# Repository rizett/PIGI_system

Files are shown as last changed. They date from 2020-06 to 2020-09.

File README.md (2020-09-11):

# PIGI_system
This repository (doi. 10.5281/zenodo.4024952) contains Matlab, LabVIEW and AutoIt software scripts to acquire and process data from the PIGI system (Izett & Tortell, 2020; Oceanography). Technical and CAD drawings are also provided.

The LabVIEW files contain scripts to acquire, display and record underway deployment data. LabVIEW files were written using version 2019, SP1. The base, full and professional development programs (require license) can be downloaded here: https://www.ni.com/en-ca/support/downloads/software-products/download.labview.html#329059. The provided installer contains the 2019 runtime engine, or it can be downloaded separately from https://www.ni.com/en-ca/support/downloads/software-products/download.labview.html#346878. 

The AutoIt files contain scripts to automatically re-start underway data acquisitions. AutoIt can be downoloaded freely here: https://www.autoitscript.com/site/autoit-tools/

The Matlab files contain scripts to read and process deployment data. An example dataset is provided. These scripts are not compatible with Octave.

The technical diagrams contain specifications for machining components of the PIGI system. Diagrams were produced using Solidworks, and can be viewed without a license. Additional Solidworks files, containing 3D CAD assembly diagrams are also included. 

References:
Izett, R. & Tortell, P. 2020. The Pressure of in-situ Gases Instrument (PIGI) for autonomous ship-board measurement of dissolved O2 and N2 in surface ocean waters. Oceanography. 33(2).https://doi.org/10.5670/oceanog.2020.214.

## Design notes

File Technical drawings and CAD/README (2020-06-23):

This folder contains technical drawings for the machined PIGI components and Solidworks 3D CAD software files.

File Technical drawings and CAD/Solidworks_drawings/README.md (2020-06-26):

This folder contains Solidworks files to visualize 3D CAD drawings. 

Open PIGI4.3_2020.SLDASM to view the assembled components, and PIGI_4.3_Part-Drawings.SLDDRW to view the part drawings (saved as PIGI4.3_Technical-drawings.PDF)

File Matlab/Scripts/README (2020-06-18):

This folder contains the scripts and functions to read and process PIGI data obtained from LabVIEW acquisitions. 

Run "process_pigi_MAIN.m" to peform the processing.

Note that additional hydrographic data (temperature and salinity), and atmospheric sea level pressure are required to perform post-processing calculations.

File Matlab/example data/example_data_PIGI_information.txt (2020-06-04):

Cruise Name: example_data
Cruise ID: ex-dat
Ship: Black Pearl
Operator Name: Izett
Optode Serial No.: 4330-2941
TDGP (mini) Serial No.: 37-465-31
Pump Type: Magnetic Drive
Instrument Location: Main Lab
Loop Calibration Samples Obtained?: YES
Time offset from TSG: 0 Hr, 3 Min, 18 Sec Behind
Data headers:
Computer JD
O2%
O2 uM
Opt. temp
mini mbar
mini temp
Flow rate [l/min]
GPS JD
GPS Lat
GPS Long
Opt raw CalPhase
Opt raw TC Phase
Opt raw C1RPh
Opt raw C2RPh
Opt raw C1 amp
Opt raw C2 amp
Opt raw Raw temp
mini raw supply voltage
mini raw Analog in 1
mini raw Analog in 2
mini raw Digital in 1
mini raw Digital in 2
Pump status (on/off)
Primary flow rate [L/min]

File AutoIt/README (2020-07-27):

This folder contains an AutoIt (https://www.autoitscript.com/site/autoit-tools/) script to automatically re-start PIGI LabVIEW acquisitions. 

The script can be edited by opening the .au3 file. After making edits, the file MUST be re-compiled into an executable (.exe) file (Right click --> compile --> rename the compiled file as run_acquisition_compiled.exe). NOTE: the file does not need to be edited in its current form to work; only edits for alternative functionality should be made as desired by the user.  

The .exe file must be referenced in the autoPIGI_underway_2020 LabVIEW program.

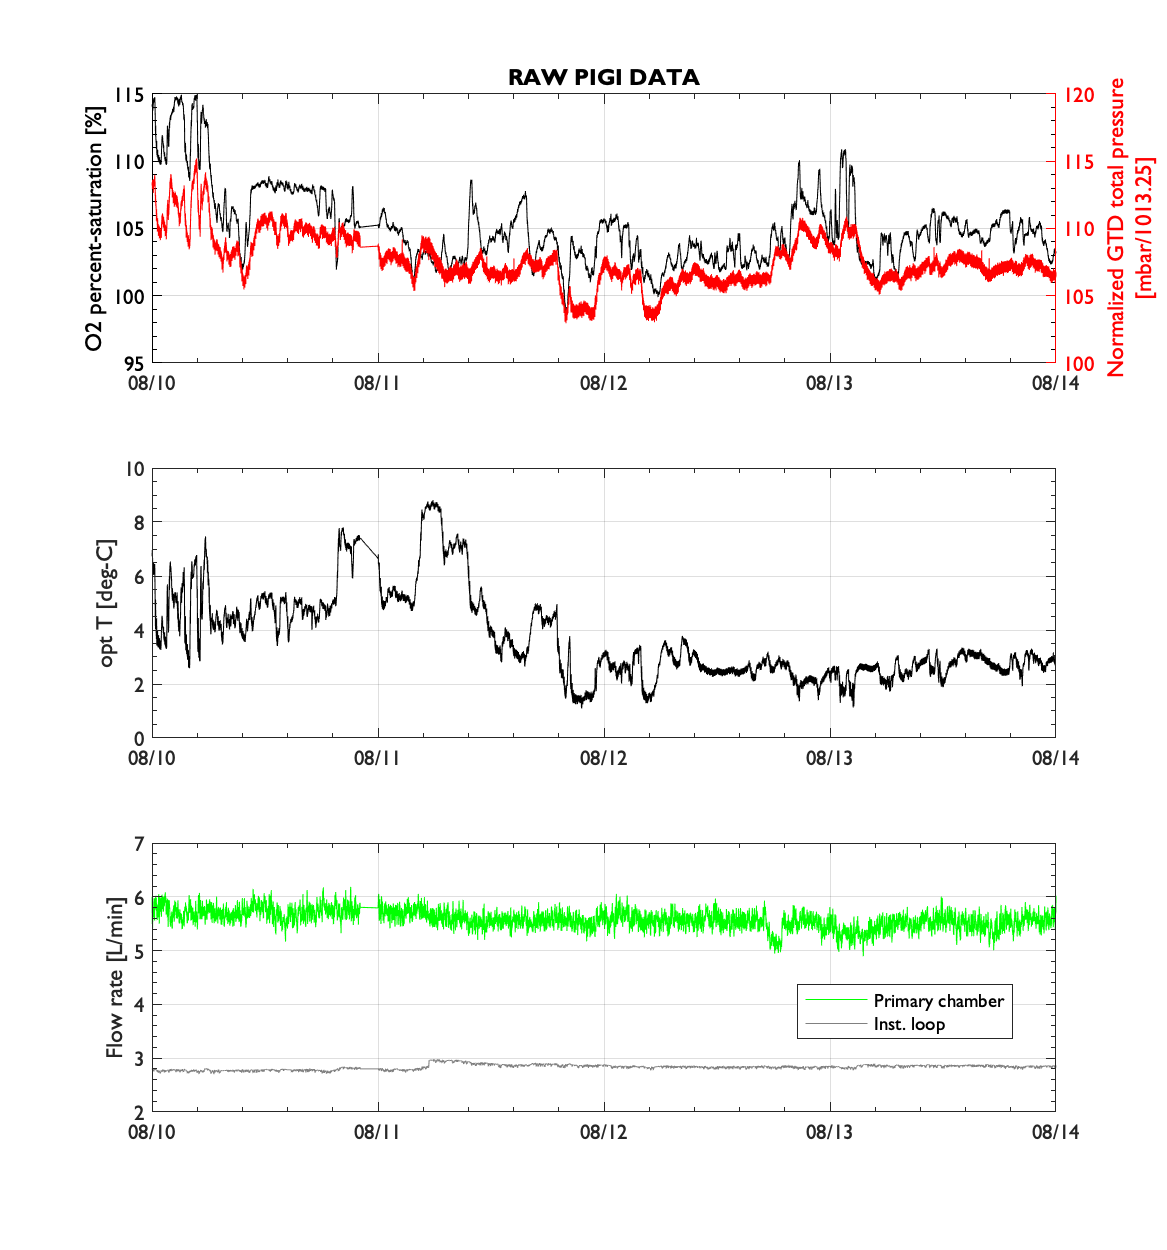
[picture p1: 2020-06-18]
Matlab/example data/example_deployment_PIGI_RAW_v20200618.tif

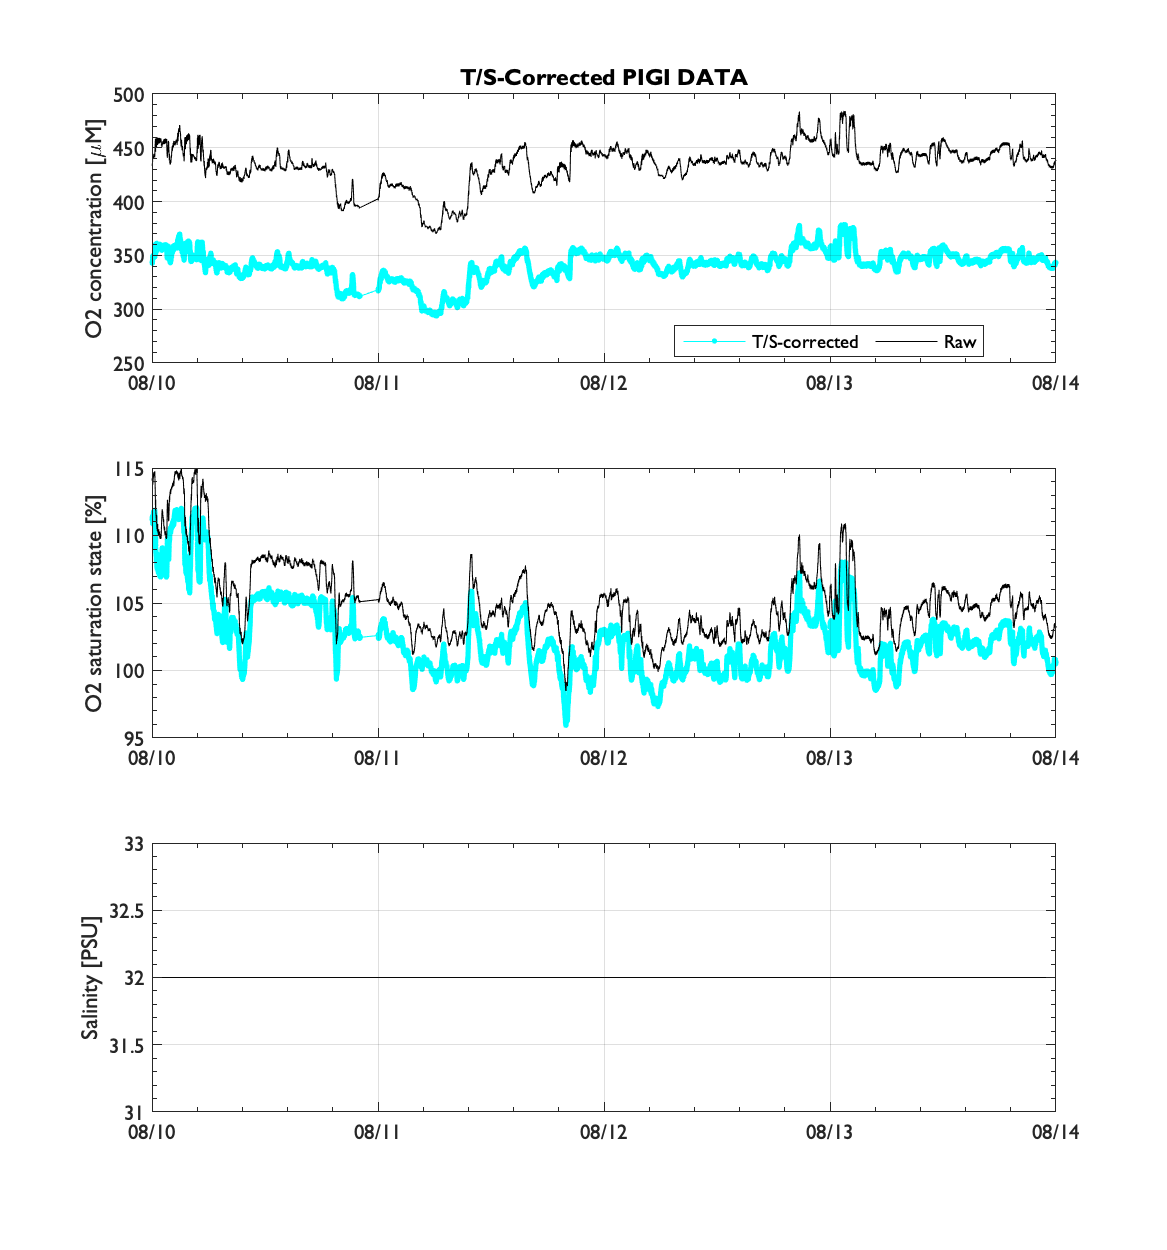
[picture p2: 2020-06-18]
Matlab/example data/example_deployment_PIGI_O2-TS-Comp_v20200618.tif

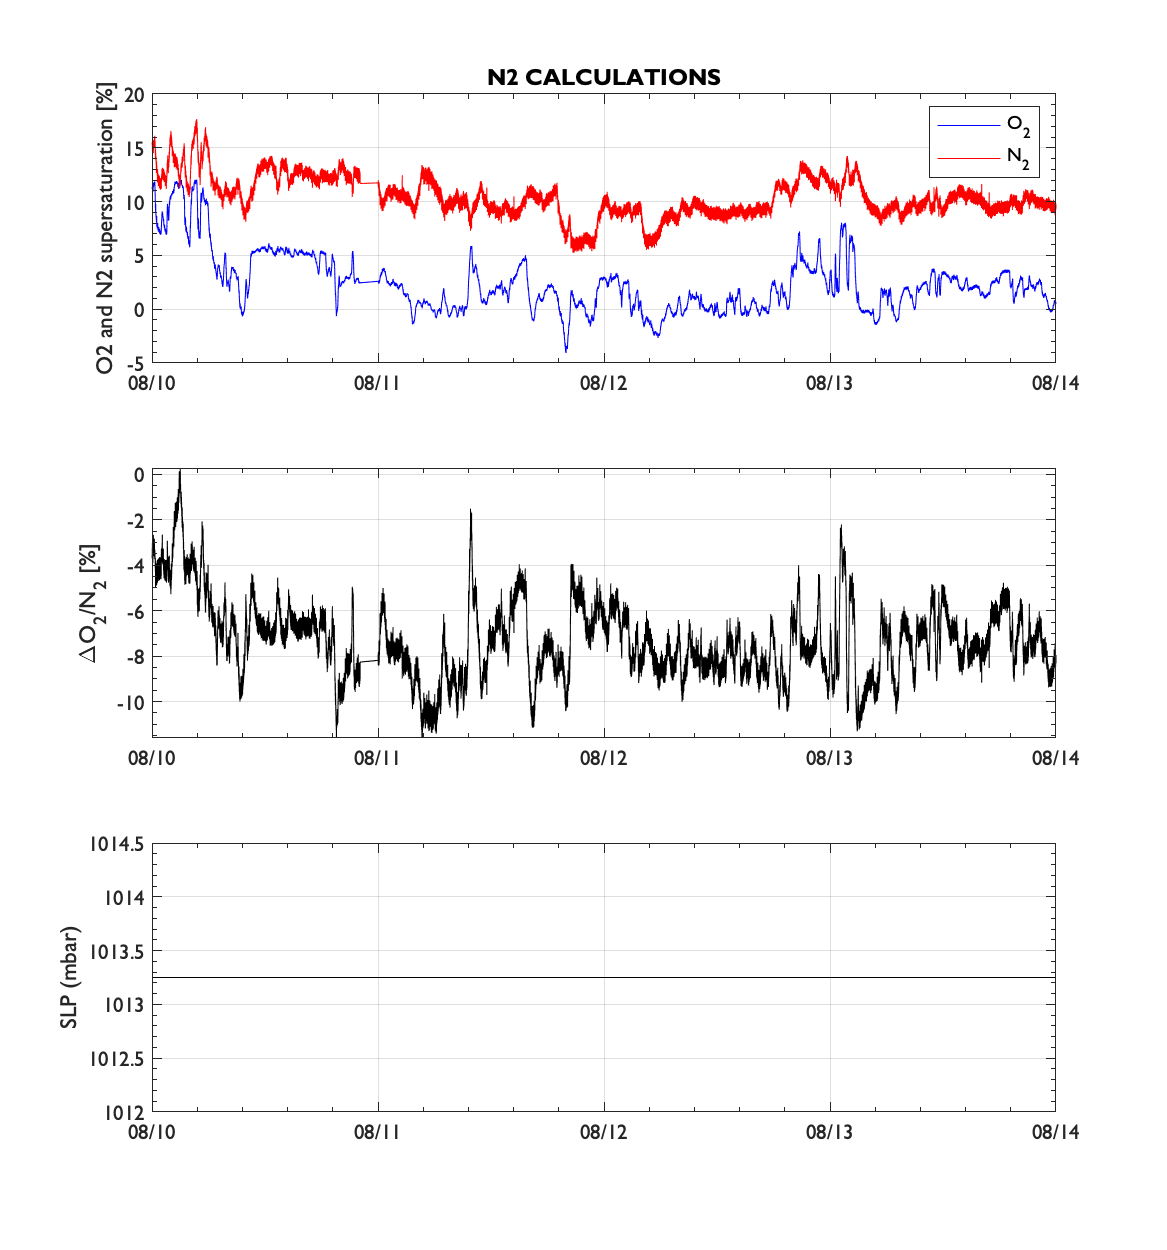
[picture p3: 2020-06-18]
Matlab/example data/example_deployment_PIGI_N2_calc.mat_v20200618.tif

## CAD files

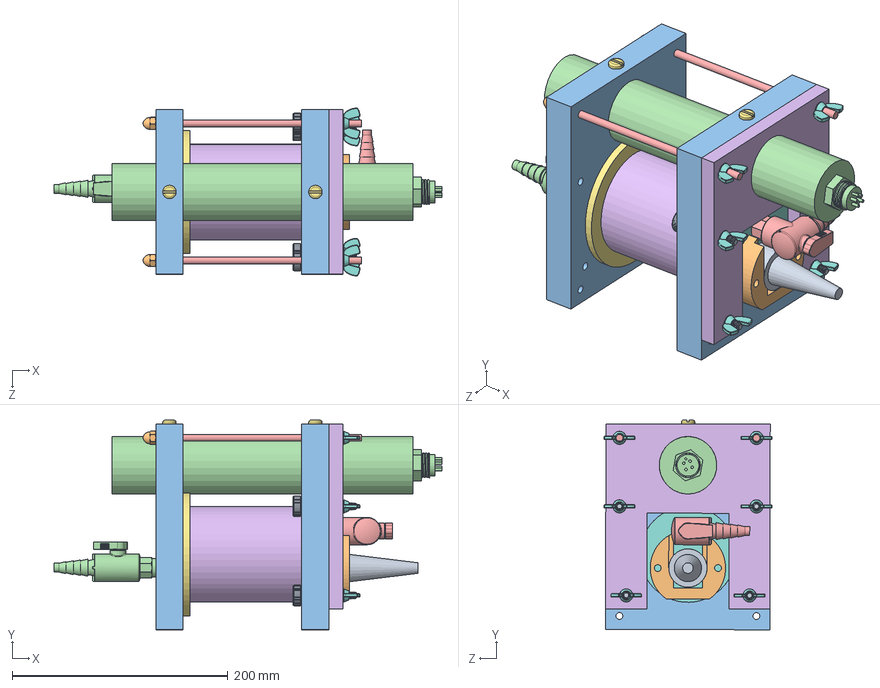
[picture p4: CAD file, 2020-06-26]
Technical drawings and CAD/Solidworks_drawings/PIGI4.3_Instrument-Chamber.SLDASM
359.6 x 194.2 x 155.6 mm
PIGI4.3_Thumb-Screw_Part34 x 4
PIGI4.3_Acorn-Nut_Part31 x 2
PIGI4.3_Optode-Chamber-Support_PartG x 2
PIGI4.3_mini-TDGP_Part2
PIGI4.3_8in-SS-rod_Part32 x 2
PIGI4.3_Optode-chamber-tube_PartC
PIGI4.3_Optode-Chamber-Inflow-Cap_PartJ
PIGI4.3_Optode-Chamber-Outflow-Cap_PartI
PIGI4.3_Optode_Part1
PIGI4.3_Optode-Support_PartK
PIGI4.3_Optode-Chamber-Outflow-Oring_Part15
PIGI4.3_Straight-Valve_Part18
PIGI4.3_Elbow-Valve_Part19
PIGI4.3_Optode-Chamber-Outflow-Stopper_PartH
PIGI4.3_Teflon-screw_Part35 x 2
PIGI4.3_Wing-Nut_Part30 x 6

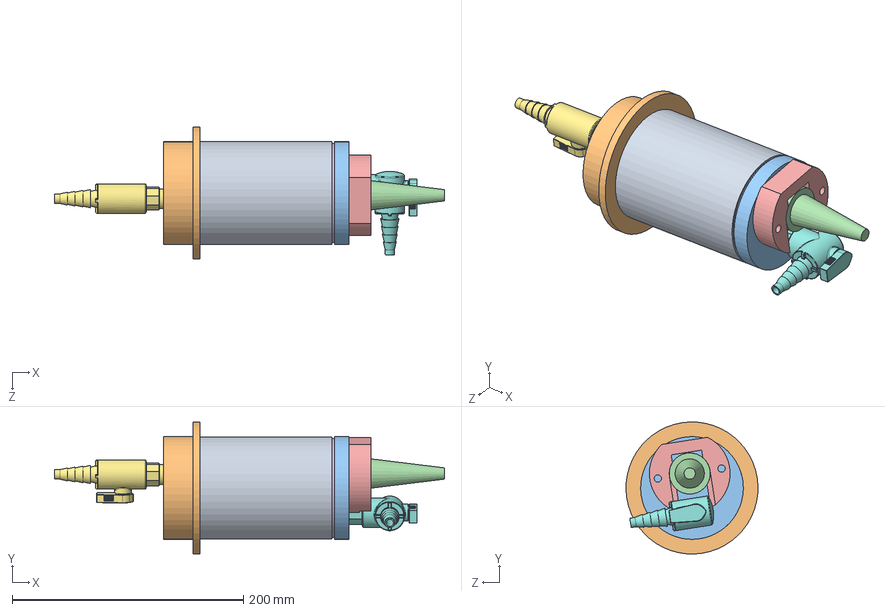
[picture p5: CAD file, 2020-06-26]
Technical drawings and CAD/Solidworks_drawings/PIGI4.3_Optode_chamber.SLDASM
337.6 x 114.2 x 114.2 mm
PIGI4.3_Optode-chamber-tube_PartC
PIGI4.3_Optode-Chamber-Inflow-Cap_PartJ
PIGI4.3_Optode-Chamber-Outflow-Cap_PartI
PIGI4.3_Optode_Part1
PIGI4.3_Optode-Support_PartK
PIGI4.3_Optode-Chamber-Outflow-Oring_Part15
PIGI4.3_Straight-Valve_Part18
PIGI4.3_Elbow-Valve_Part19

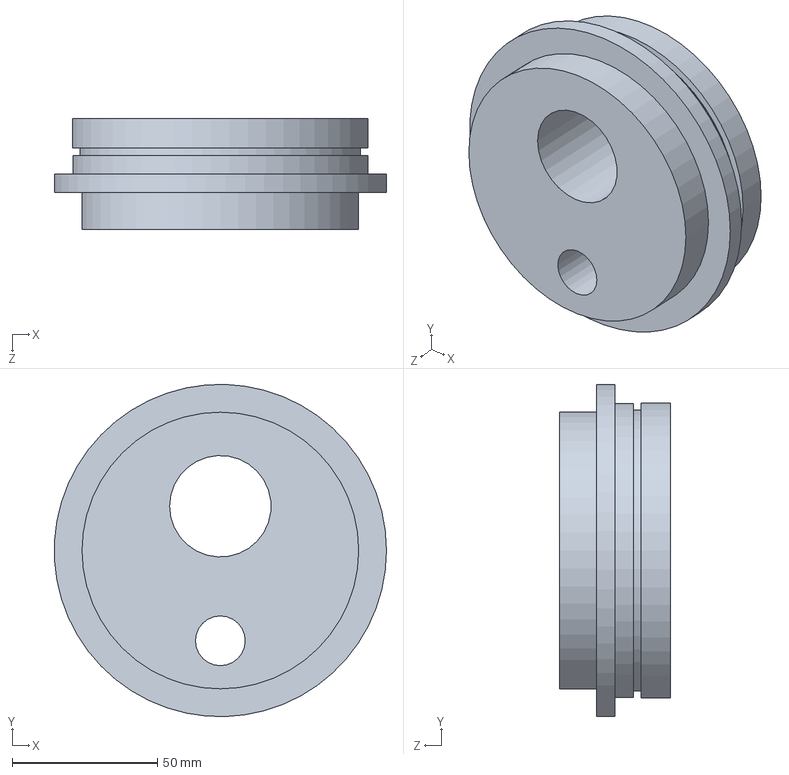
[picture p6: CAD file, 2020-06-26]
Technical drawings and CAD/Solidworks_drawings/PIGI4.3_Primary-chamber-inflow-cap_PartD.SLDPRT
114.3 x 114.4 x 38.1 mm

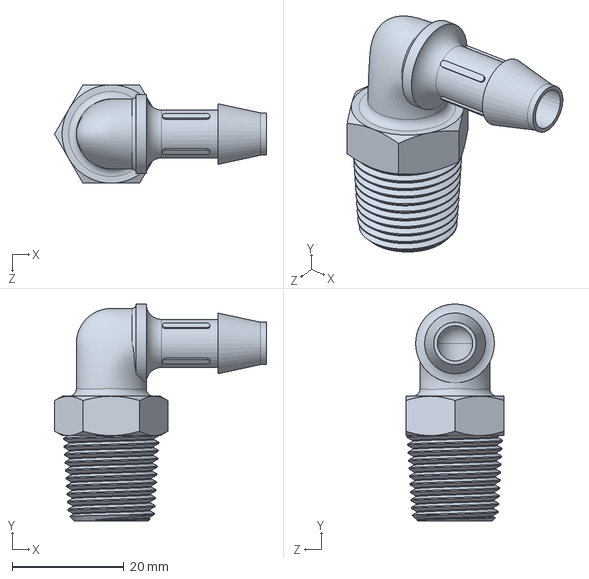
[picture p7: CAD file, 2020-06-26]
Technical drawings and CAD/Solidworks_drawings/PIGI4.3_Barbed-Adapter_Part27.SLDPRT
37.9 x 38.8 x 17.6 mm

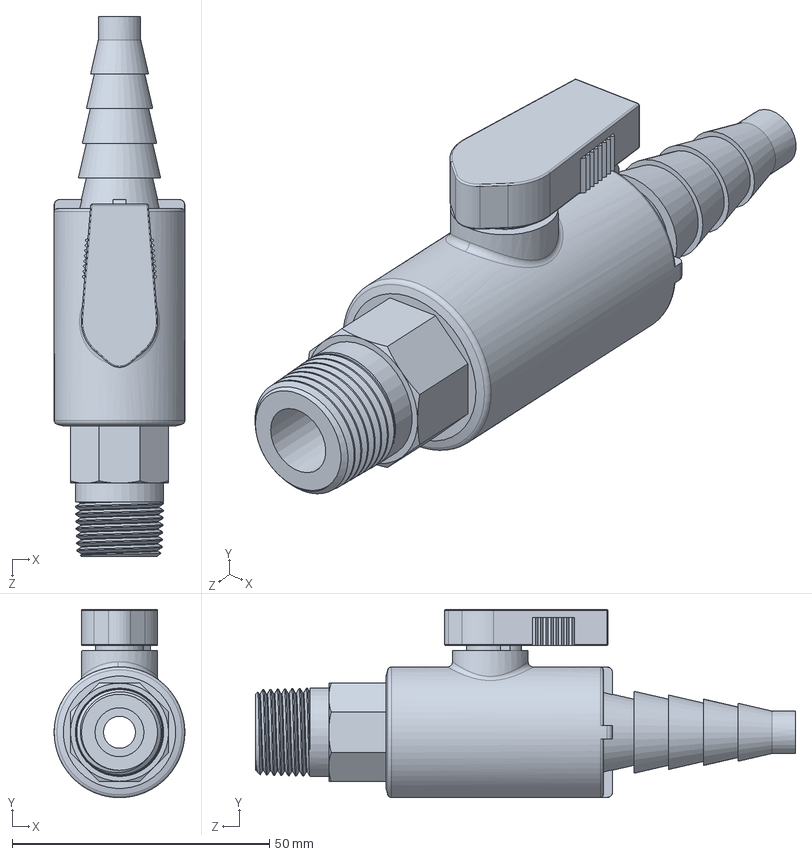
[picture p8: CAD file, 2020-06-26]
Technical drawings and CAD/Solidworks_drawings/PIGI4.3_Straight-Valve_Part18.SLDPRT
25.4 x 36.6 x 104.9 mm

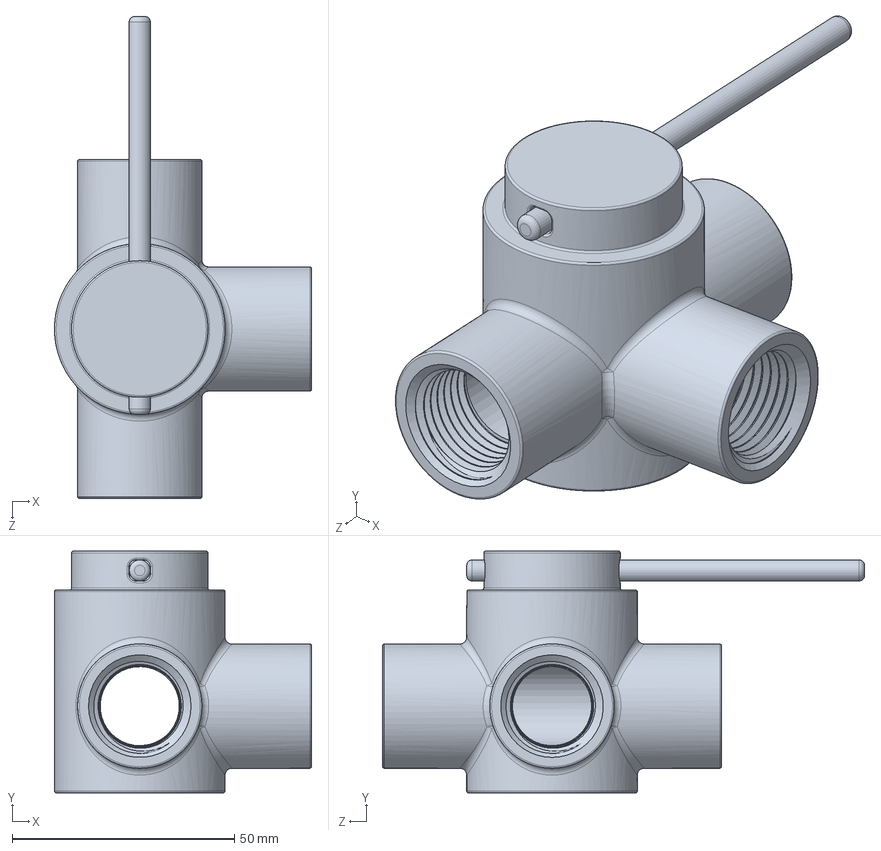
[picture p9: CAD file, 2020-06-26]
Technical drawings and CAD/Solidworks_drawings/PIGI4.3_3-Way-Valve_Part26.SLDPRT
57.8 x 54.4 x 108.3 mm

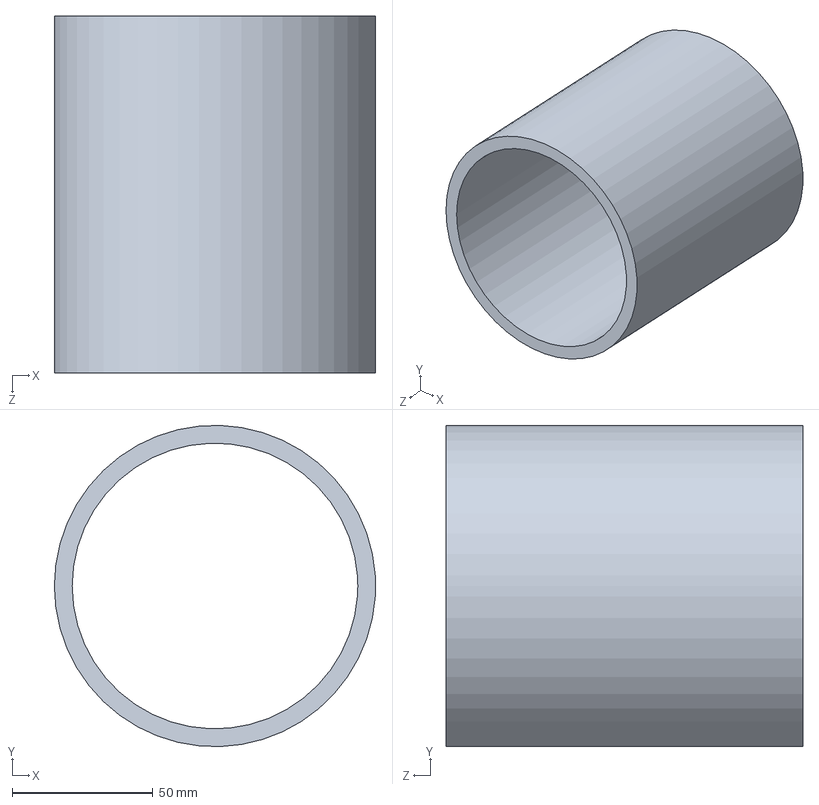
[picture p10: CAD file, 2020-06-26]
Technical drawings and CAD/Solidworks_drawings/PIGI4.3_Primary-chamber-tube-PartB.SLDPRT
114.3 x 114.2 x 127.0 mm

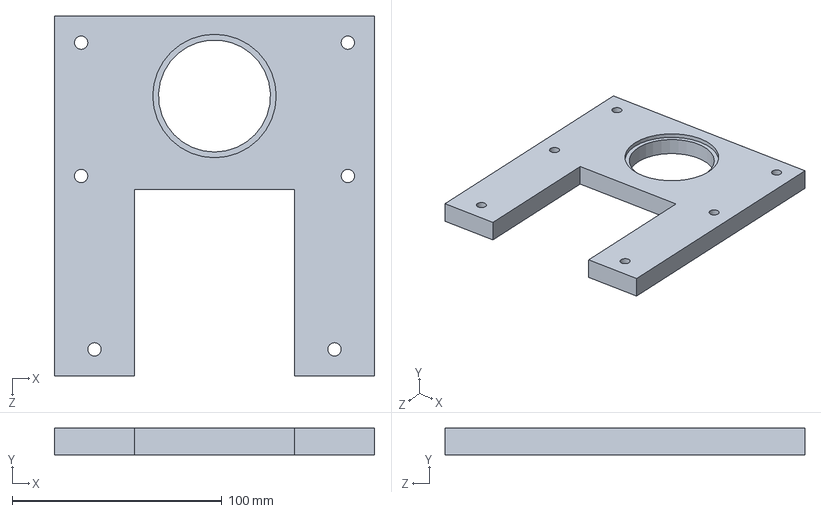
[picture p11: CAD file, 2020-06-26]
Technical drawings and CAD/Solidworks_drawings/PIGI4.3_Optode-Chamber-Outflow-Stopper_PartH.SLDPRT
152.4 x 12.7 x 171.4 mm

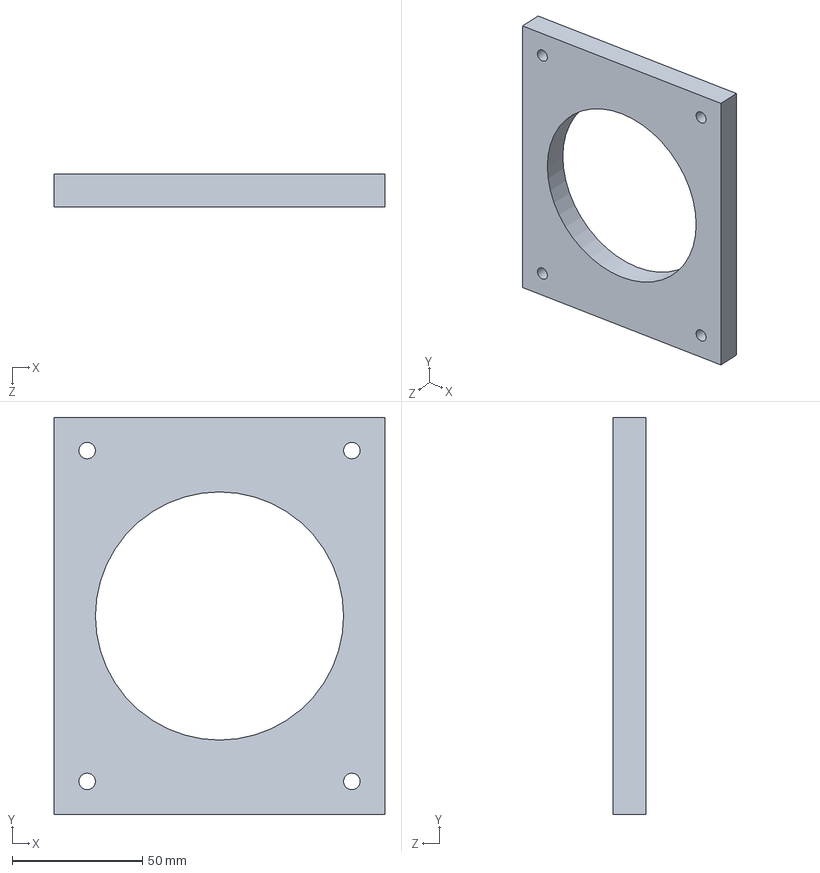
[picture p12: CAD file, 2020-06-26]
Technical drawings and CAD/Solidworks_drawings/PIGI4.3_Primary-chamber-supports_PartF.SLDPRT
127.0 x 152.4 x 12.7 mm

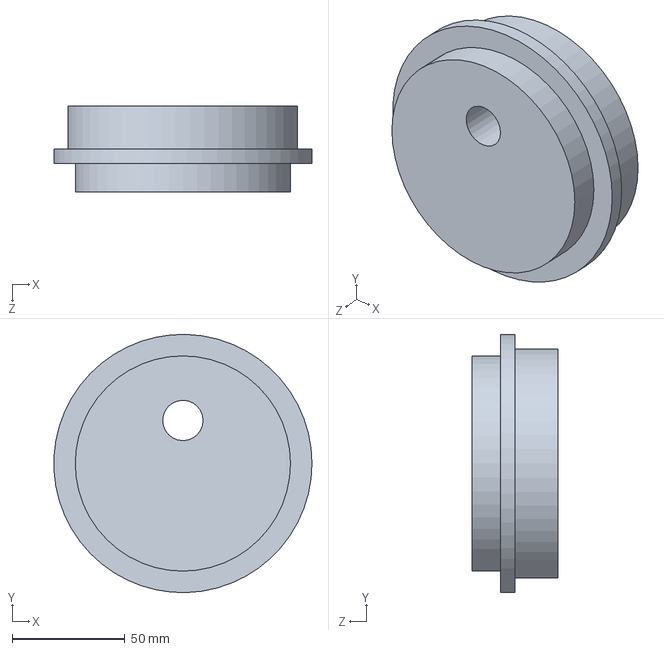
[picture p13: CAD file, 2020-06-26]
Technical drawings and CAD/Solidworks_drawings/PIGI4.3_Primary-chamber-outflow-cap_PartE.SLDPRT
114.2 x 114.2 x 38.1 mm

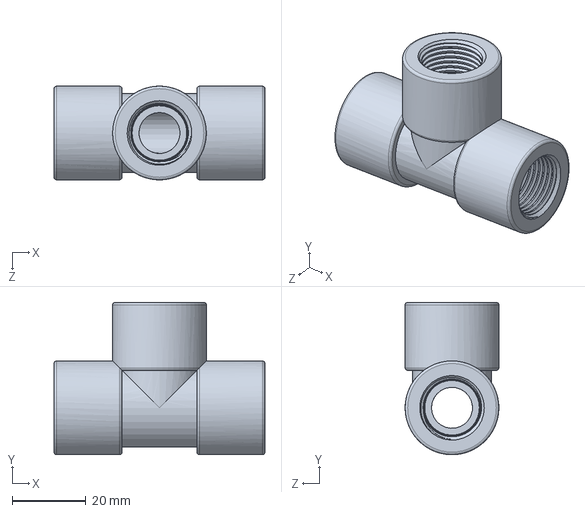
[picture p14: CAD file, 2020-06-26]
Technical drawings and CAD/Solidworks_drawings/PIGI4.3_T-Junction_Part22.SLDPRT
57.1 x 41.3 x 25.4 mm

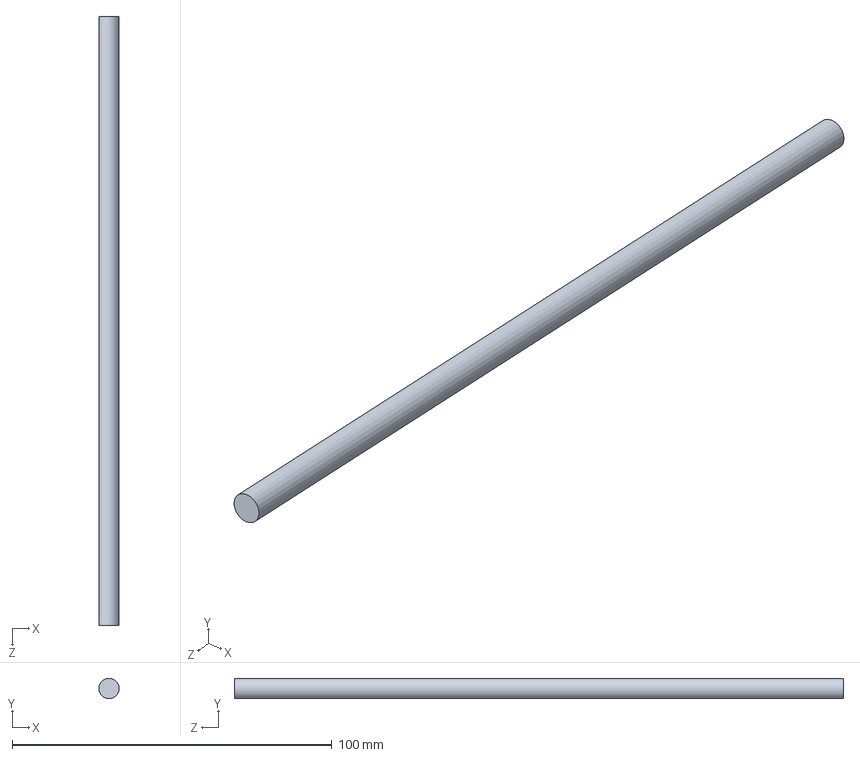
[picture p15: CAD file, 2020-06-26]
Technical drawings and CAD/Solidworks_drawings/PIGI4.3_8in-SS-rod_Part32.SLDPRT
6.35 x 6.35 x 190.5 mm

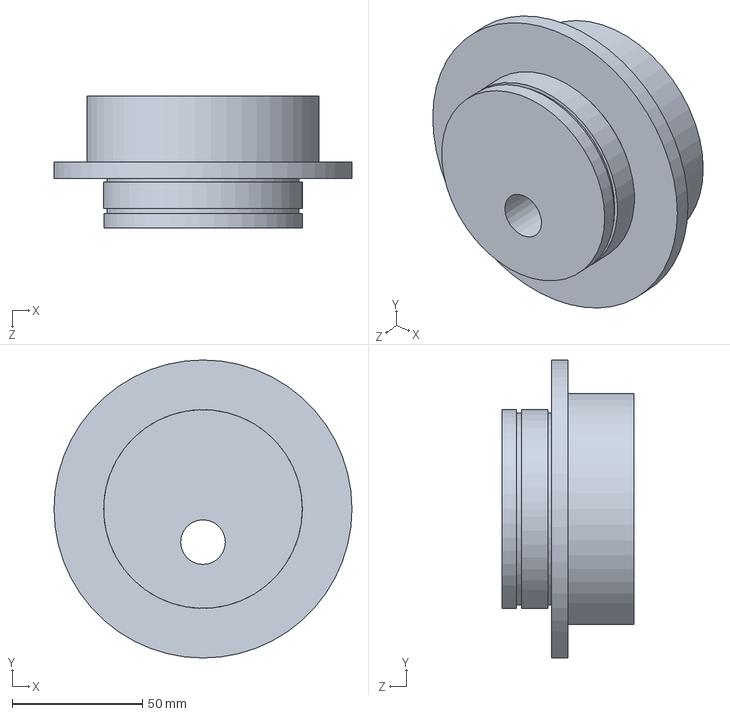
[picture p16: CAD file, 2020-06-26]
Technical drawings and CAD/Solidworks_drawings/PIGI4.3_Optode-Chamber-Inflow-Cap_PartJ.SLDPRT
114.3 x 114.3 x 50.8 mm

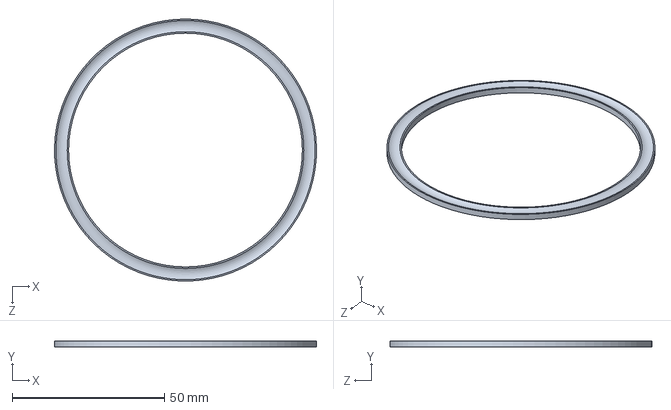
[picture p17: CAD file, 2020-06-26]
Technical drawings and CAD/Solidworks_drawings/PIGI4.3_Optode-Chamber-Outflow-Oring_Part15.SLDPRT
85.9 x 1.93 x 85.9 mm

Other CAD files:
Technical drawings and CAD/Solidworks_drawings/PIGI4.3_Optode-Chamber-Support_PartG.SLDPRT
Technical drawings and CAD/Solidworks_drawings/PIGI4.3_Check-Valve_Part25.SLDPRT
Technical drawings and CAD/Solidworks_drawings/PIGI4.3_Check-Valve_Part23.SLDPRT
Technical drawings and CAD/Solidworks_drawings/PIGI4.3_Debubbler-Tube_Part8.SLDPRT
Technical drawings and CAD/Solidworks_drawings/PIGI4.3_7in-SS-rod_Part32.SLDPRT
Technical drawings and CAD/Solidworks_drawings/PIGI4.3_9in-SS-rod_Part32.SLDPRT
Technical drawings and CAD/Solidworks_drawings/PIGI4.3_Acorn-Nut_Part31.SLDPRT
Technical drawings and CAD/Solidworks_drawings/PIGI4.3_Chamber-Base-PartA.SLDPRT
Technical drawings and CAD/Solidworks_drawings/PIGI4.3_Compression-Pads_Part36.SLDPRT
Technical drawings and CAD/Solidworks_drawings/PIGI4.3_Debubbler-Bulkhead-Connector_Part9.SLDPRT
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

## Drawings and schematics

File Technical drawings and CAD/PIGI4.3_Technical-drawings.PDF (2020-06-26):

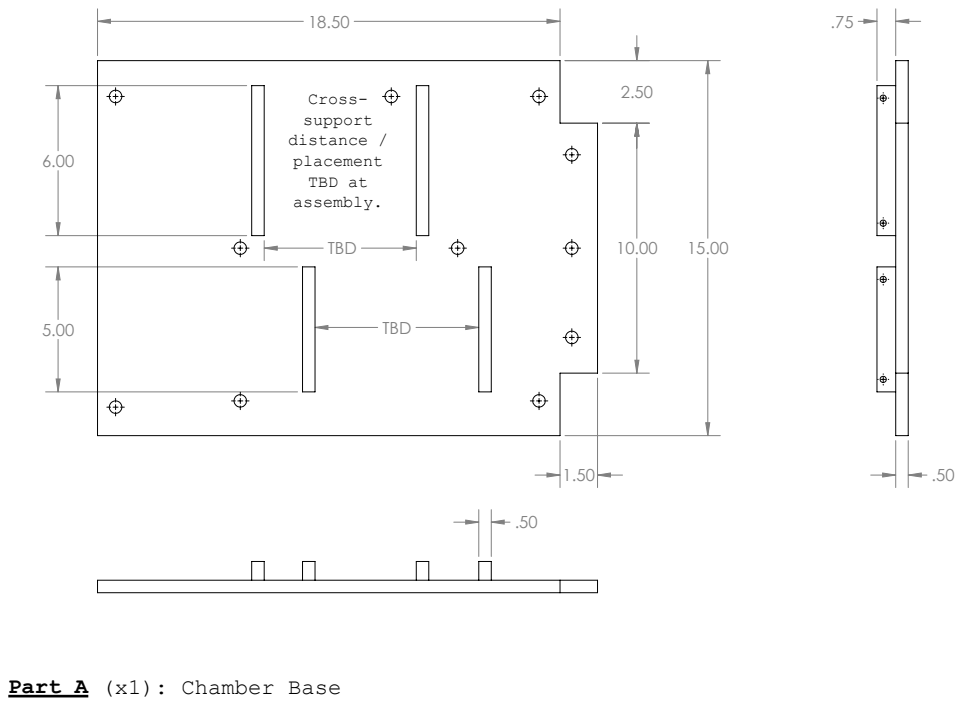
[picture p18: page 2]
distance / TBD at

Part A (x1): Chamber Base

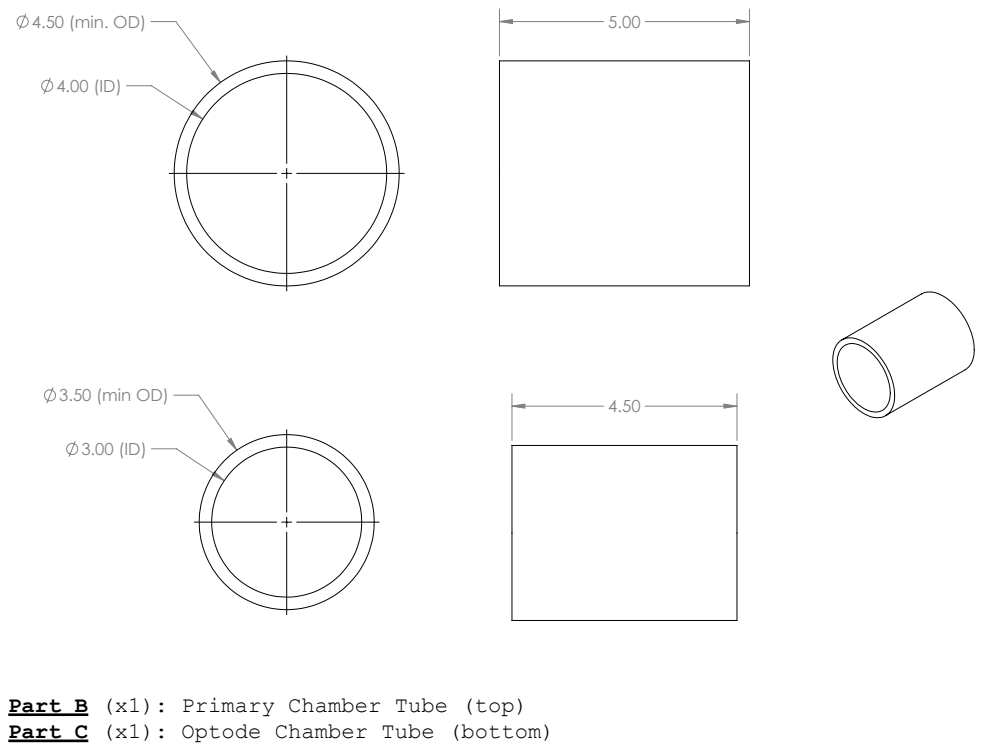
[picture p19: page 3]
4.50 (min. OD); 3.50 (min OD)

Part B (x1): Primary Chamber Tube (top)
Part C (x1): Optode Chamber Tube (bottom)

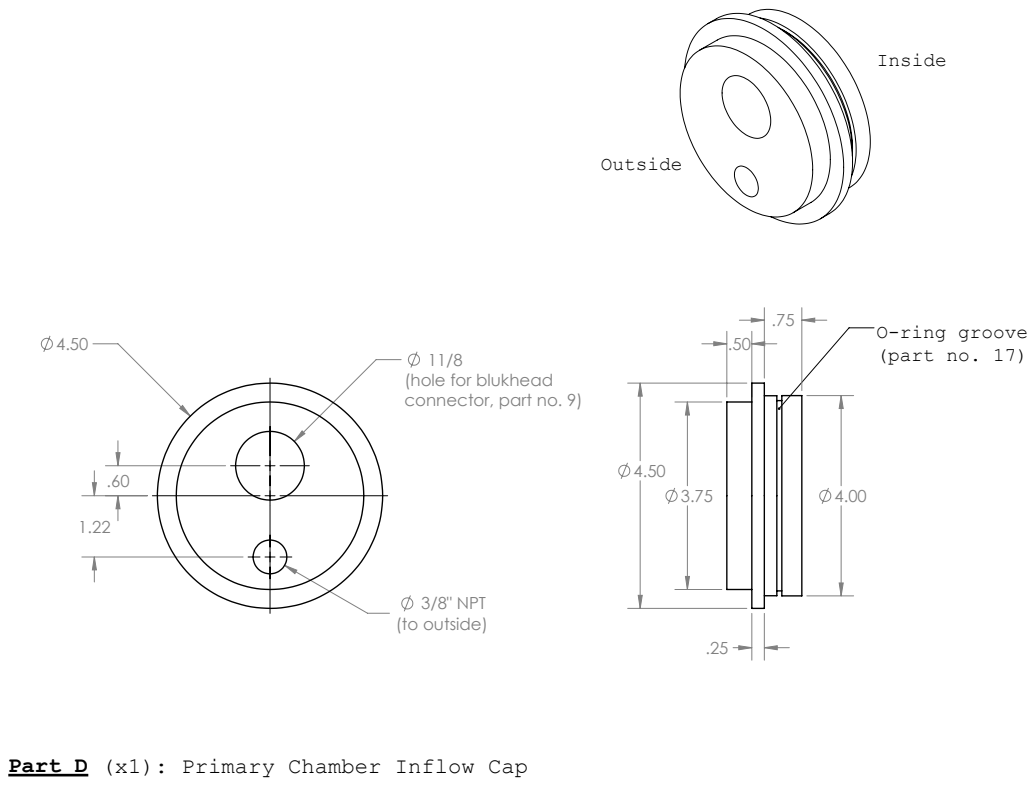
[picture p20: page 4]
3/8" NPT (to outside); O-ring groove (part no. 17)

(hole for blukhead
connector, part no. 9)

Part D (x1): Primary Chamber Inflow Cap

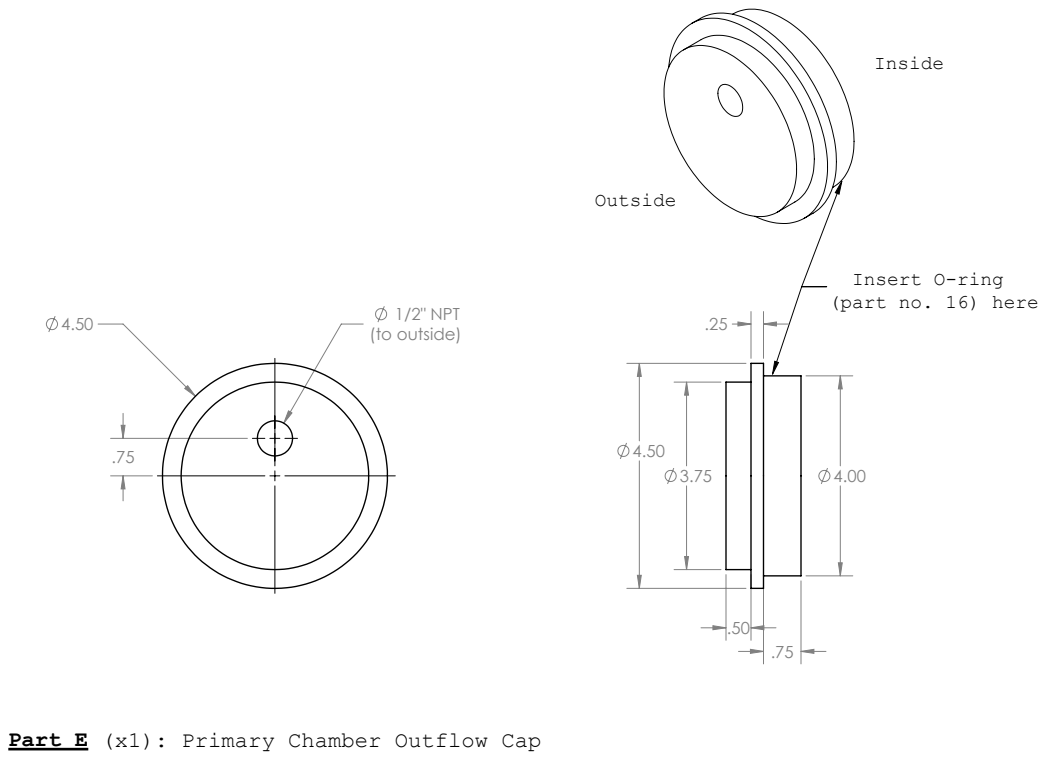
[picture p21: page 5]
1/2" NPT (to outside)

Insert O-ring
(part no. 16) here

Part E (x1): Primary Chamber Outflow Cap

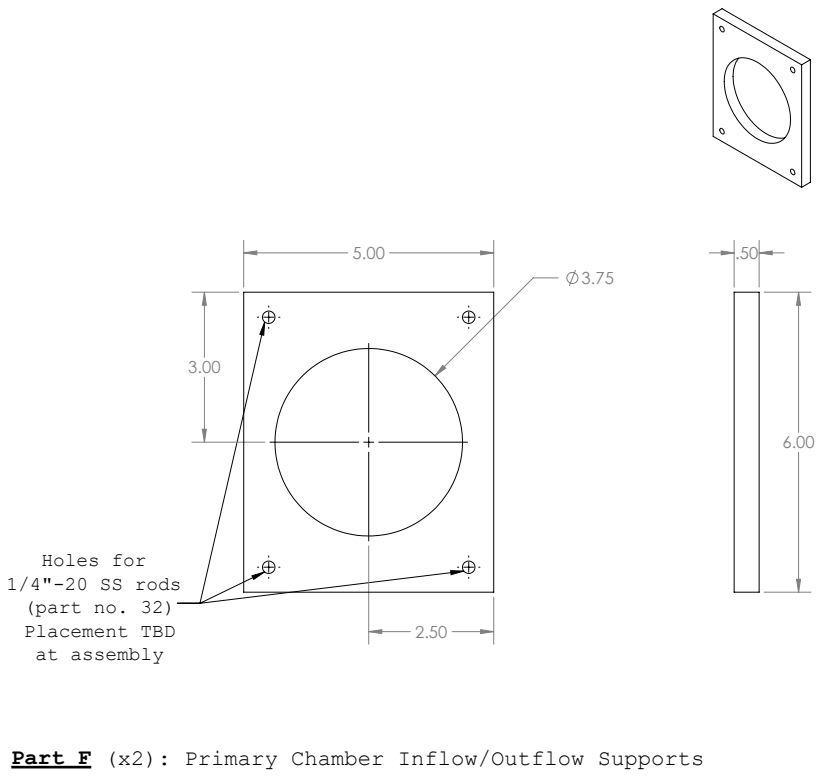
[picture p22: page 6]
Holes for 1/4"-20 SS rods (part no. 32) Placement TBD at assembly

Part F (x2): Primary Chamber Inflow/Outflow Supports

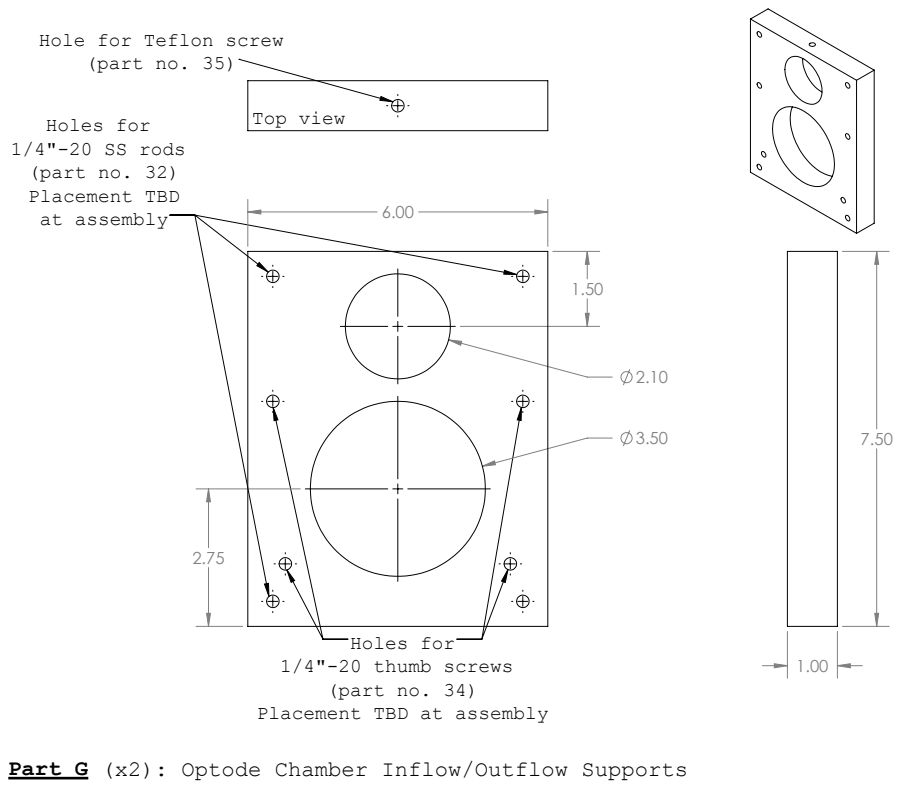
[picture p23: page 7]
Top view

Hole for Teflon screw
(part no. 35)
Holes for
1/4"-20 SS rods
(part no. 32)
Placement TBD
at assembly

1/4"-20 thumb screws
(part no. 34)
Placement TBD at assembly

Part G (x2): Optode Chamber Inflow/Outflow Supports

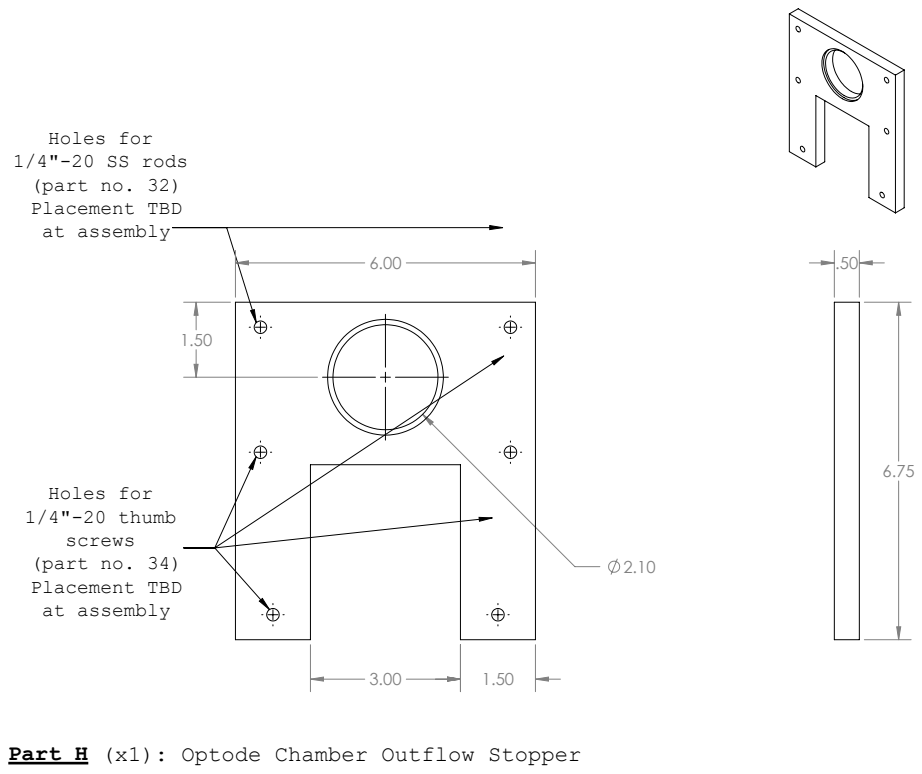
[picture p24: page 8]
Holes for 1/4"-20 SS rods (part no. 32) Placement TBD at assembly; Holes for 1/4"-20 thumb (part no. 34) Placement TBD at assembly

Part H (x1): Optode Chamber Outflow Stopper

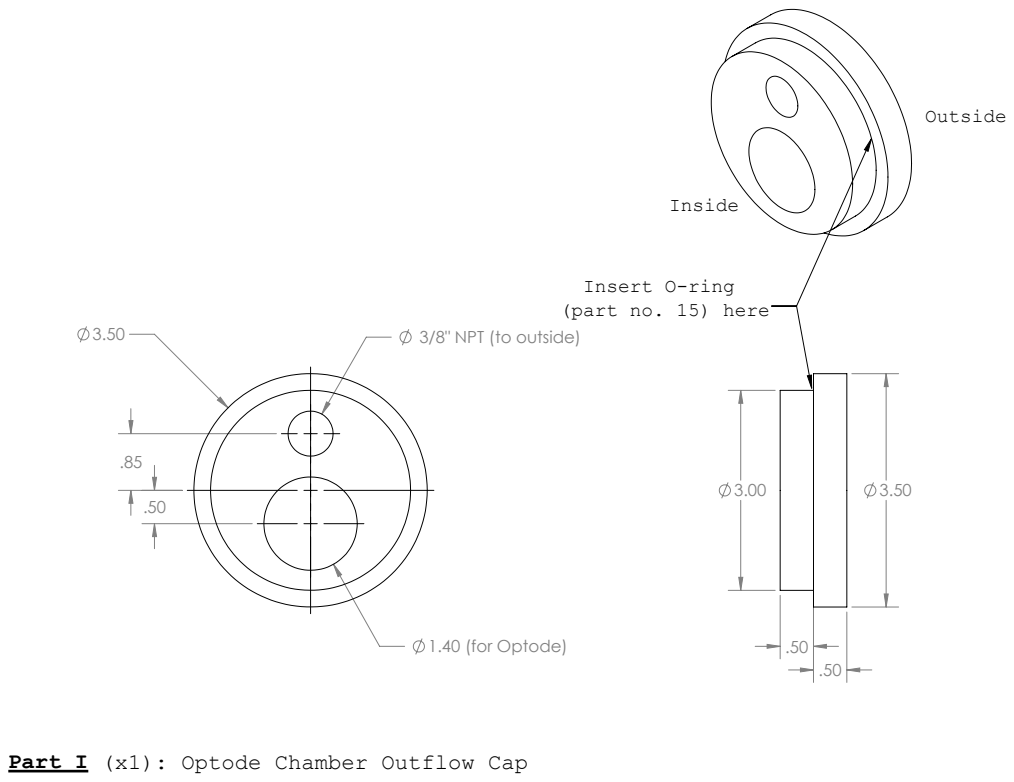
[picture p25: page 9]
1.40 (for Optode)

Insert O-ring
(part no. 15) here

3/8" NPT (to outside)

Part I (x1): Optode Chamber Outflow Cap

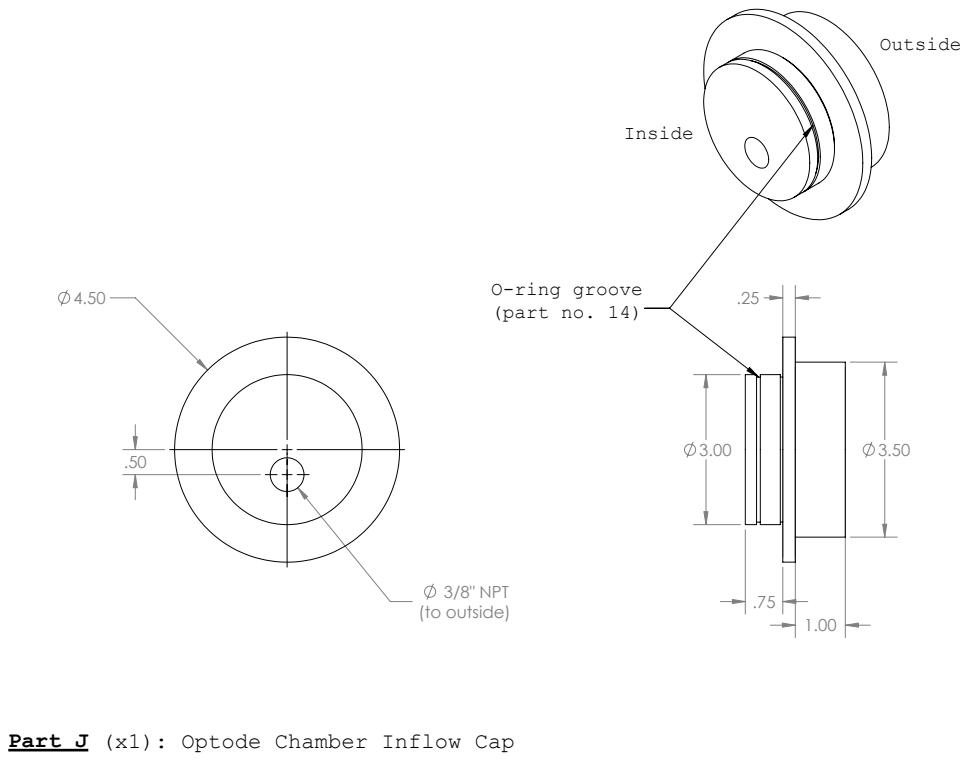
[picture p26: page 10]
3/8" NPT (to outside); O-ring groove (part no. 14)

Part J (x1): Optode Chamber Inflow Cap

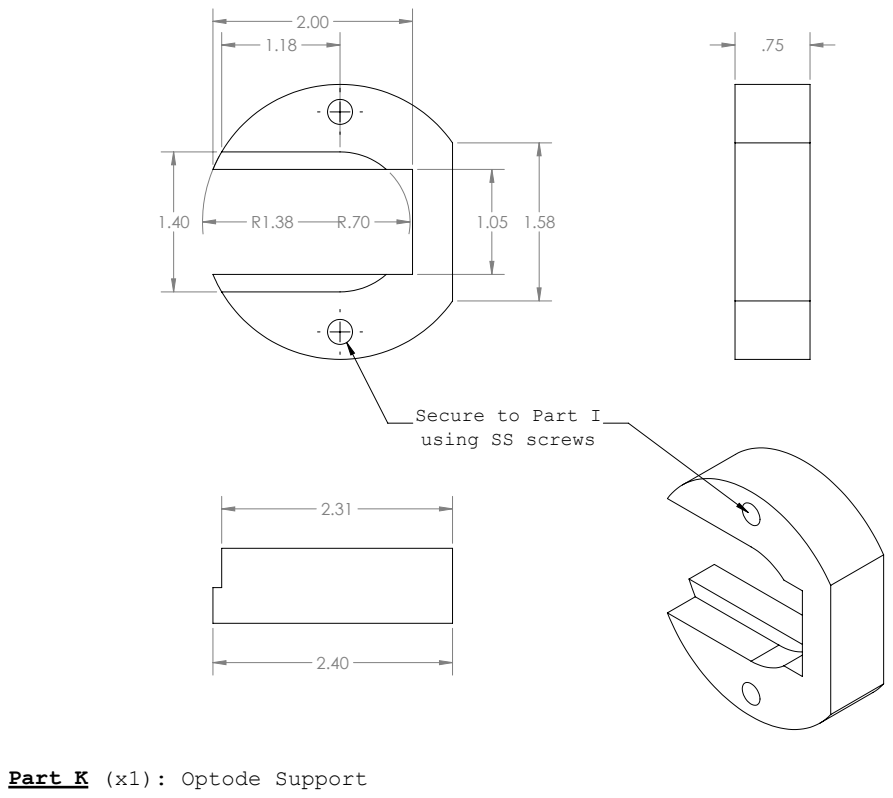
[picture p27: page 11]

Secure to Part I
using SS screws

Part K (x1): Optode Support
